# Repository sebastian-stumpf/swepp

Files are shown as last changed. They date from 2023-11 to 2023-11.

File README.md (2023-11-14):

# swepp

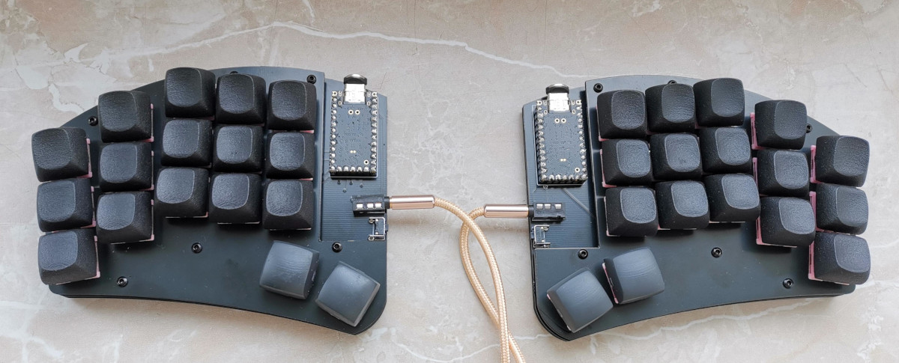
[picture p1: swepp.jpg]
swepp


## Attention

I'm a hobbyist/amateur at best. So there may be things that aren't optimized. That being said I've had the files
in the `gerbers/` directory manufactured at JLC with 1.6mm thickness and they work just fine with my fork of the qmk repository
directory. So if you decide to use this, then please be advised that I'm not providing any sort of liability and you should
exercise some caution.

## Case

There are three options for the case: The first one is a simple FR4 stack. You'll need some M2 spacers and screws to fix it all
together. Plates and bottoms are reversible. The second option is a simple tray case. You'll need M2 heat inserts and screws to
fix the plate to the bottom. If you don't like the 3d printed plate you can also use the FR4 plate with spacers in this case.
The final option is a massive gasket mounted case that hides the switches.

## BOM

| Quantity | Item | Comment |
| ---  | --- | --- |
| 2 | Helios or Liatris Controller | |
| 2 | IC-Sockets+Pins for MCU | Optional but recommended |
| 2 | TRRS Sockets | |
| 2 | SKHLLBA010 buttons | |
| 34 | MX Hotswap Sockets | |
| 34 | MX Switches + Keycaps | |
| 12 | M2 Screws | (countersunk for gasket case) |
| 12 | M2 heat inserts | Only for the 3d printed cases |

## Firmware

See [my fork](https://github.com/sebastian-stumpf/qmk_firmware/tree/sepp/keyboards/swepp) of the qmk repository. Nothing special here.
You can just copy the code over to your own repository and adjust the keymap.

## Feedback

I'm always happy to hear your opinions about this and if you decide to build this board then please do send me a picture of it.

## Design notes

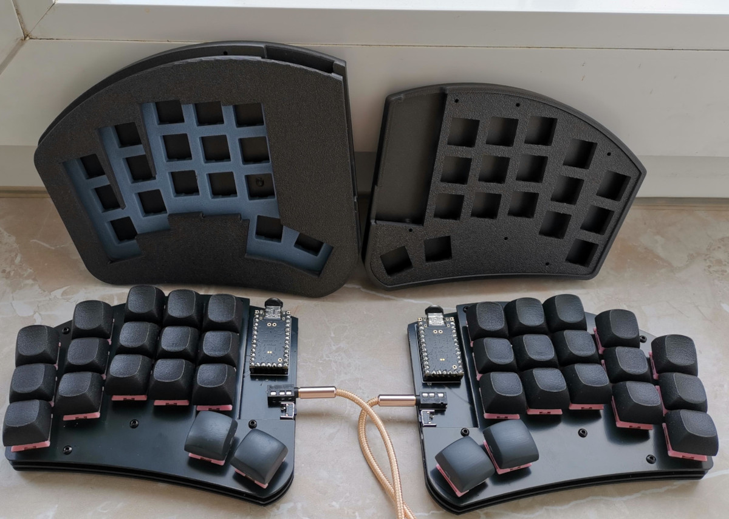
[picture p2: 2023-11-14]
case.jpg

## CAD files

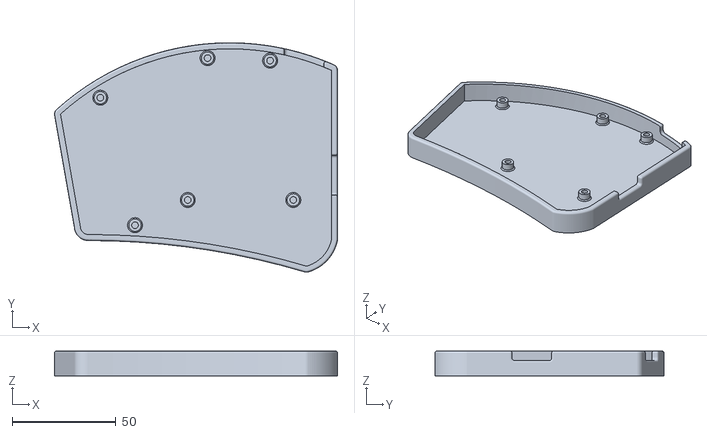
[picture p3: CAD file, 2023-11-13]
cad/case-tray-case.stl
136.2 x 110.4 x 12.0

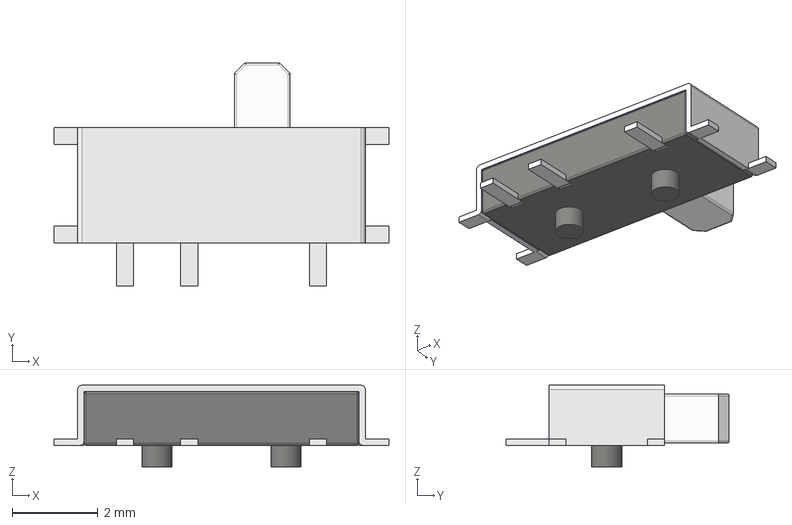
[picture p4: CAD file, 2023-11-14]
pcb/sepp/models/MSK12C02.step
7.80 x 5.20 x 1.90 mm

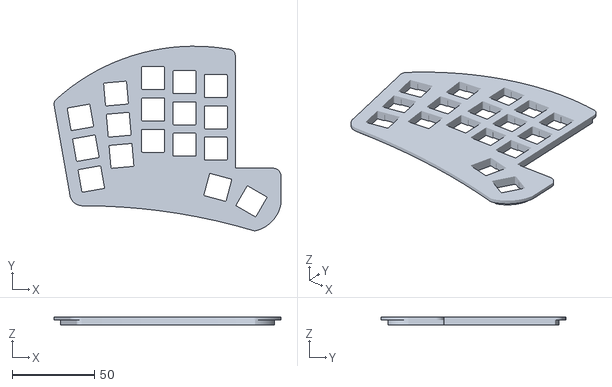
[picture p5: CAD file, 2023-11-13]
cad/case-gasket-plate.stl
138.2 x 112.3 x 5.00

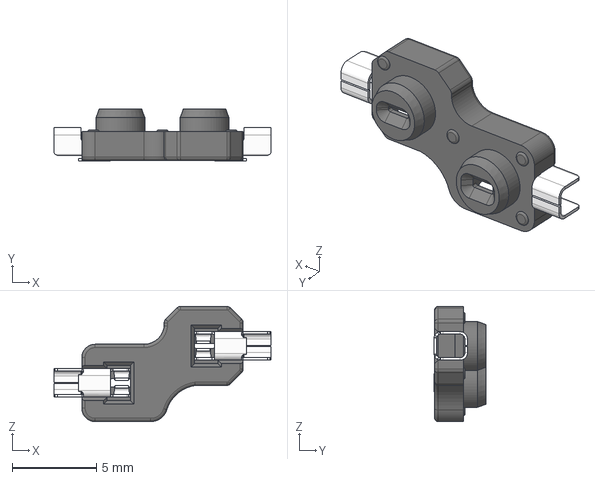
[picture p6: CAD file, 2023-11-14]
pcb/sepp/models/HS_Kailh_Choc.step
12.9 x 3.09 x 6.85 mm
pin x 2
socket

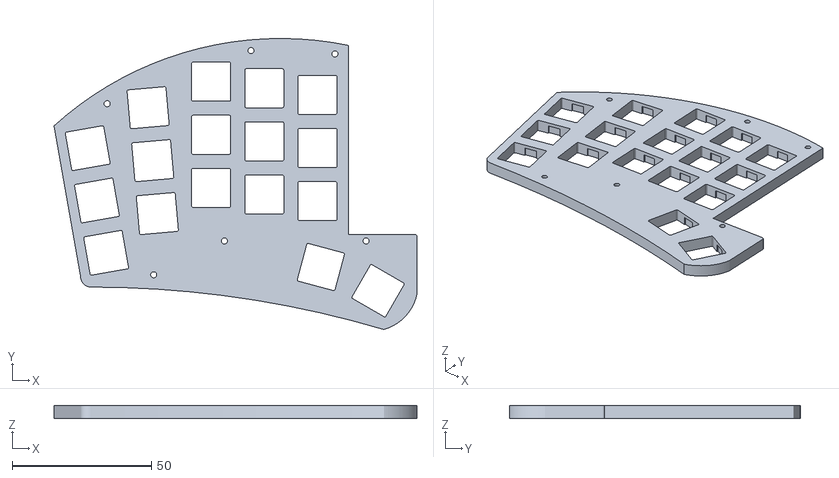
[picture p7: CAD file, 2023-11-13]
cad/case-tray-alternate-plate.stl
130.2 x 104.4 x 4.50

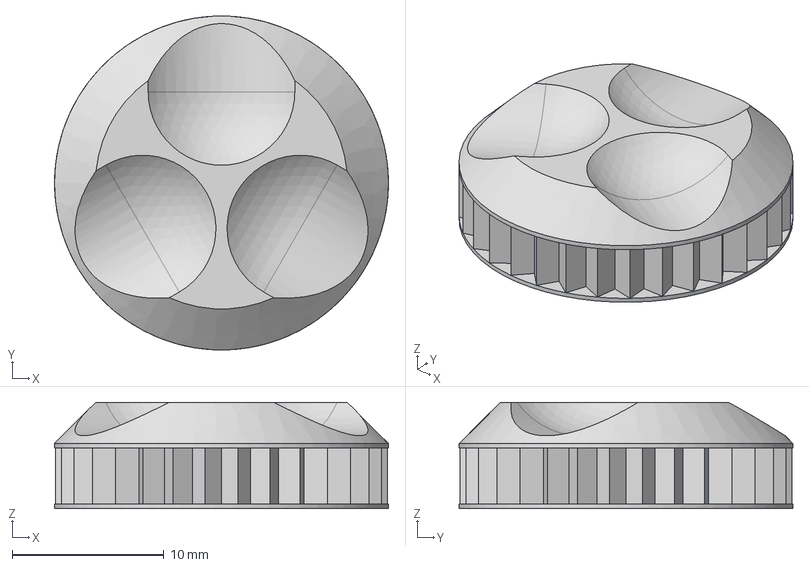
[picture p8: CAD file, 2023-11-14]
pcb/sepp/models/GEIST_EC12knob_v02_06.step
22.0 x 22.0 x 7.00 mm

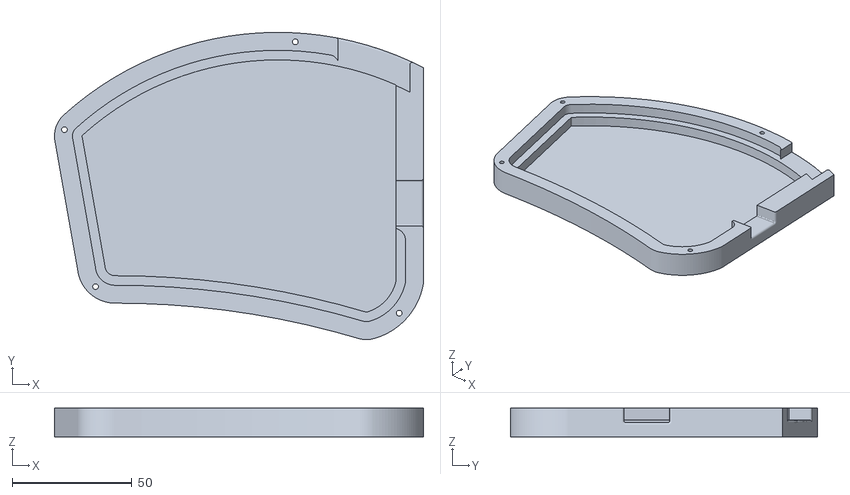
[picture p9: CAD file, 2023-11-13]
cad/case-gasket-case.stl
154.1 x 128.3 x 12.0

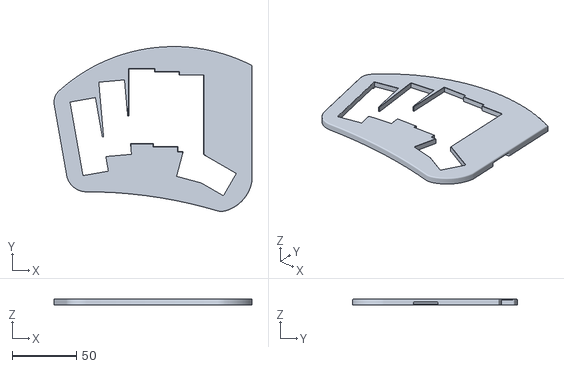
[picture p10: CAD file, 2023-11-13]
cad/case-gasket-shell.stl
154.1 x 128.3 x 5.00

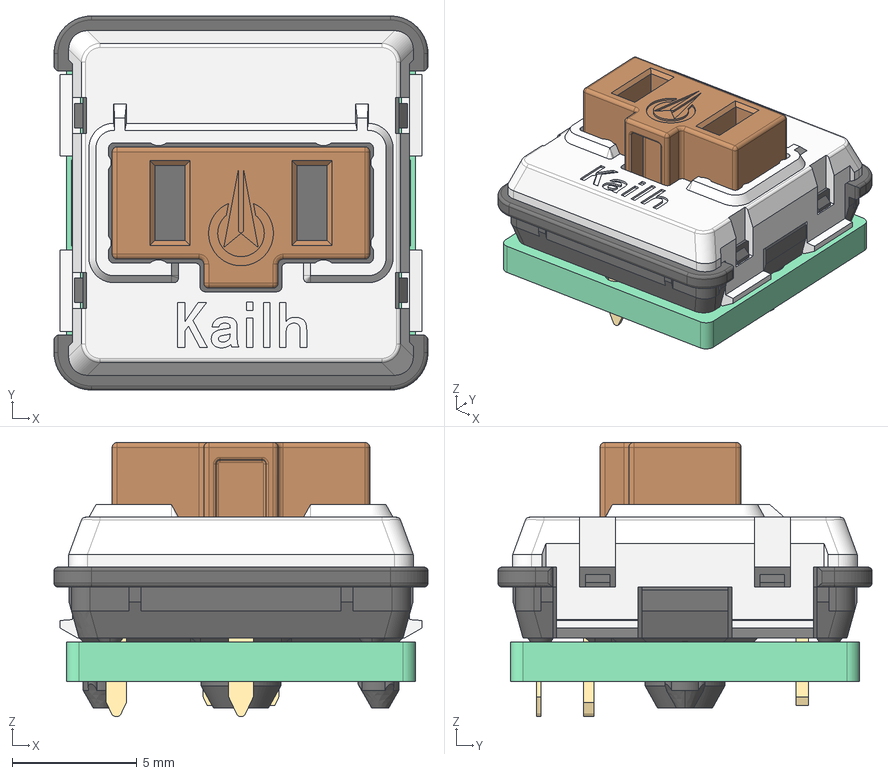
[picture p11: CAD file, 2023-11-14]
pcb/sepp/models/pg1350.step
15.0 x 15.0 x 11.0 mm

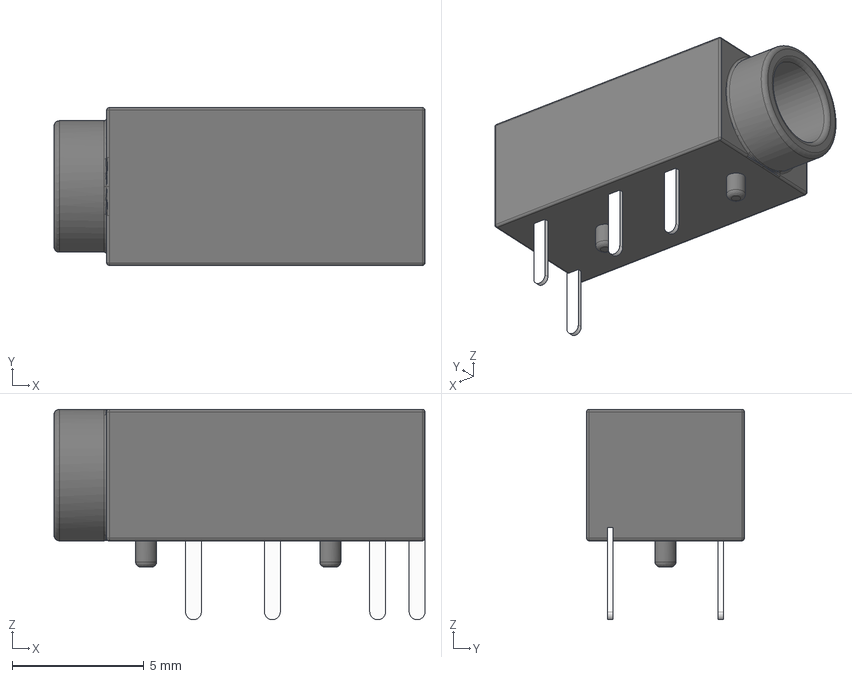
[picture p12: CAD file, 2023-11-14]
pcb/sepp/models/CON_MJ-4PP-9.step
14.1 x 6.00 x 8.00 mm

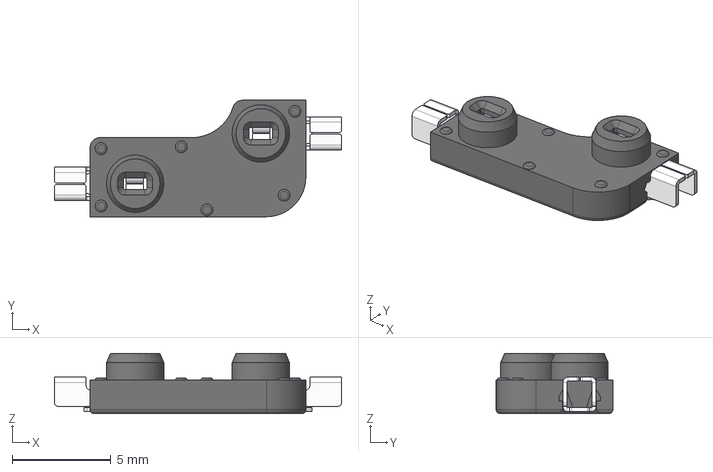
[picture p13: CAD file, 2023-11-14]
pcb/sepp/models/HS_Kailh_MX.step
14.5 x 5.89 x 3.05 mm
Contact x 2

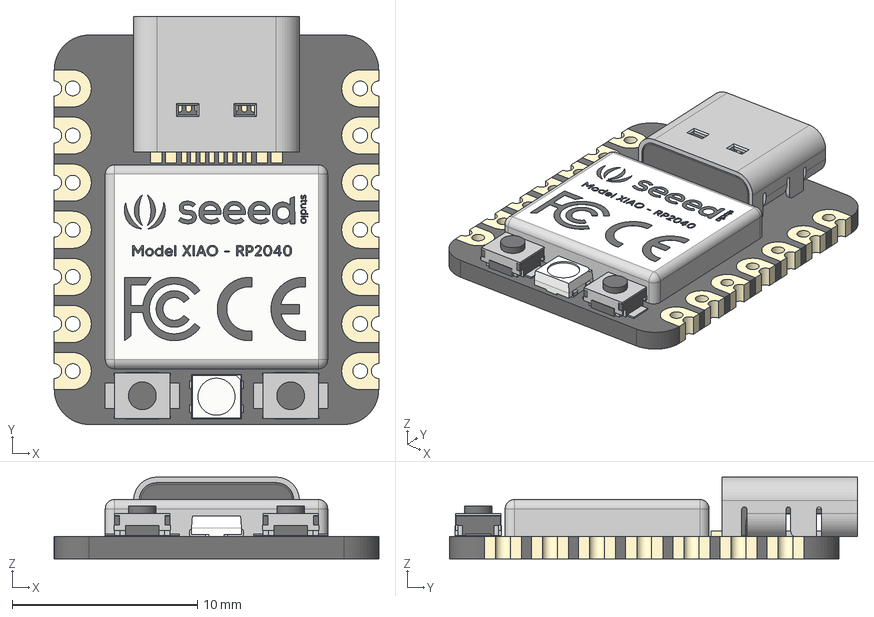
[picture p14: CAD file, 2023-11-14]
pcb/sepp/models/xiao_rp2040.step
17.5 x 22.0 x 4.40 mm
type-c v2
smd_button v3
DOUT
DIN
VSS
VDD
smd_button v3(Mirror)

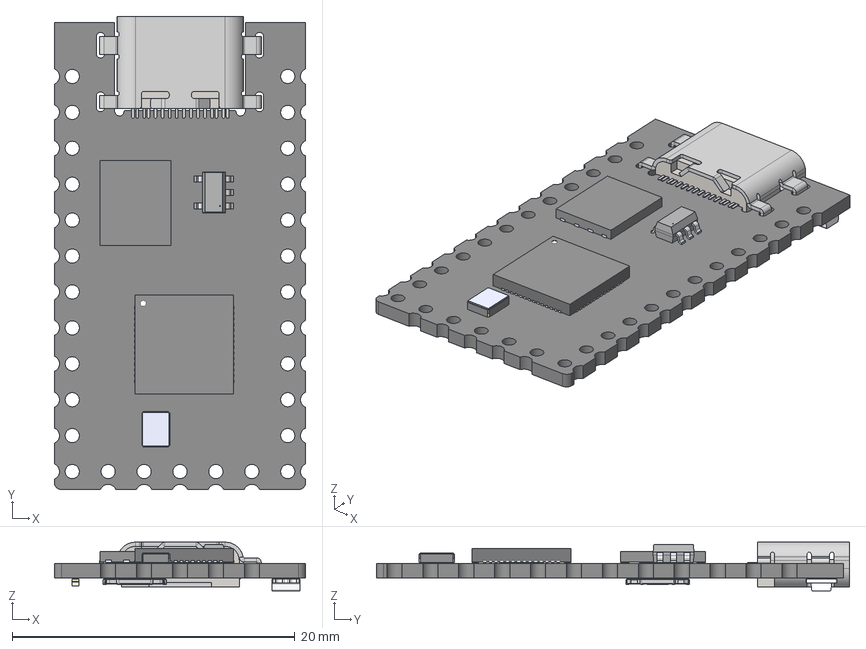
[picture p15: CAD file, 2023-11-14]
pcb/sepp/models/Liatris.step
17.8 x 33.5 x 3.44 mm
RP2040 PCB

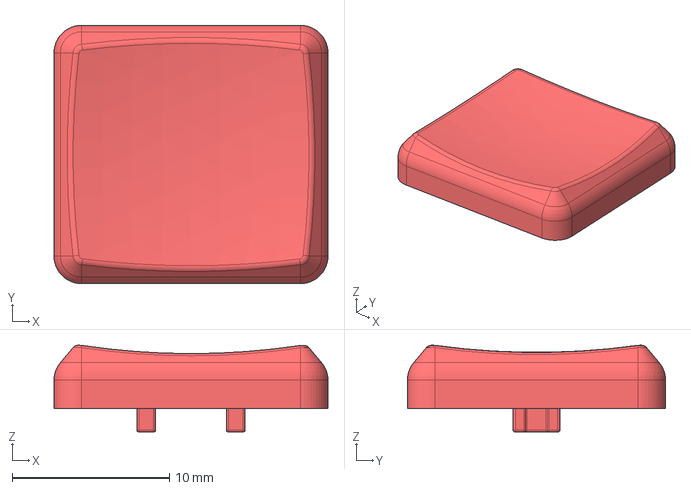
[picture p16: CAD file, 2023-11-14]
pcb/sepp/models/MBK-1u.step
17.4 x 16.4 x 5.52 mm

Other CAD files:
pcb/sepp/models/SW_MSK12C02.step
pcb/sepp/models/fpc-connector-breakout.step
pcb/sepp/models/tact-switch.step
pcb/sepp/models/pg1350-mbk.step
pcb/sepp/models/EC11-THT-15F-black.step
pcb/sepp/models/EC12E-085.step
pcb/sepp/models/LED_SK6812MINI-E.step
pcb/sepp/models/SKRTLAE010.step
pcb/sepp/models/SW_PUSH_6mm.step
pcb/sepp/models/SW_SKHLLC.step
pcb/sepp/models/abomination-trackpad-holder.step
pcb/sepp/models/cherry mx.STEP
pcb/sepp/models/mx_kecap.step

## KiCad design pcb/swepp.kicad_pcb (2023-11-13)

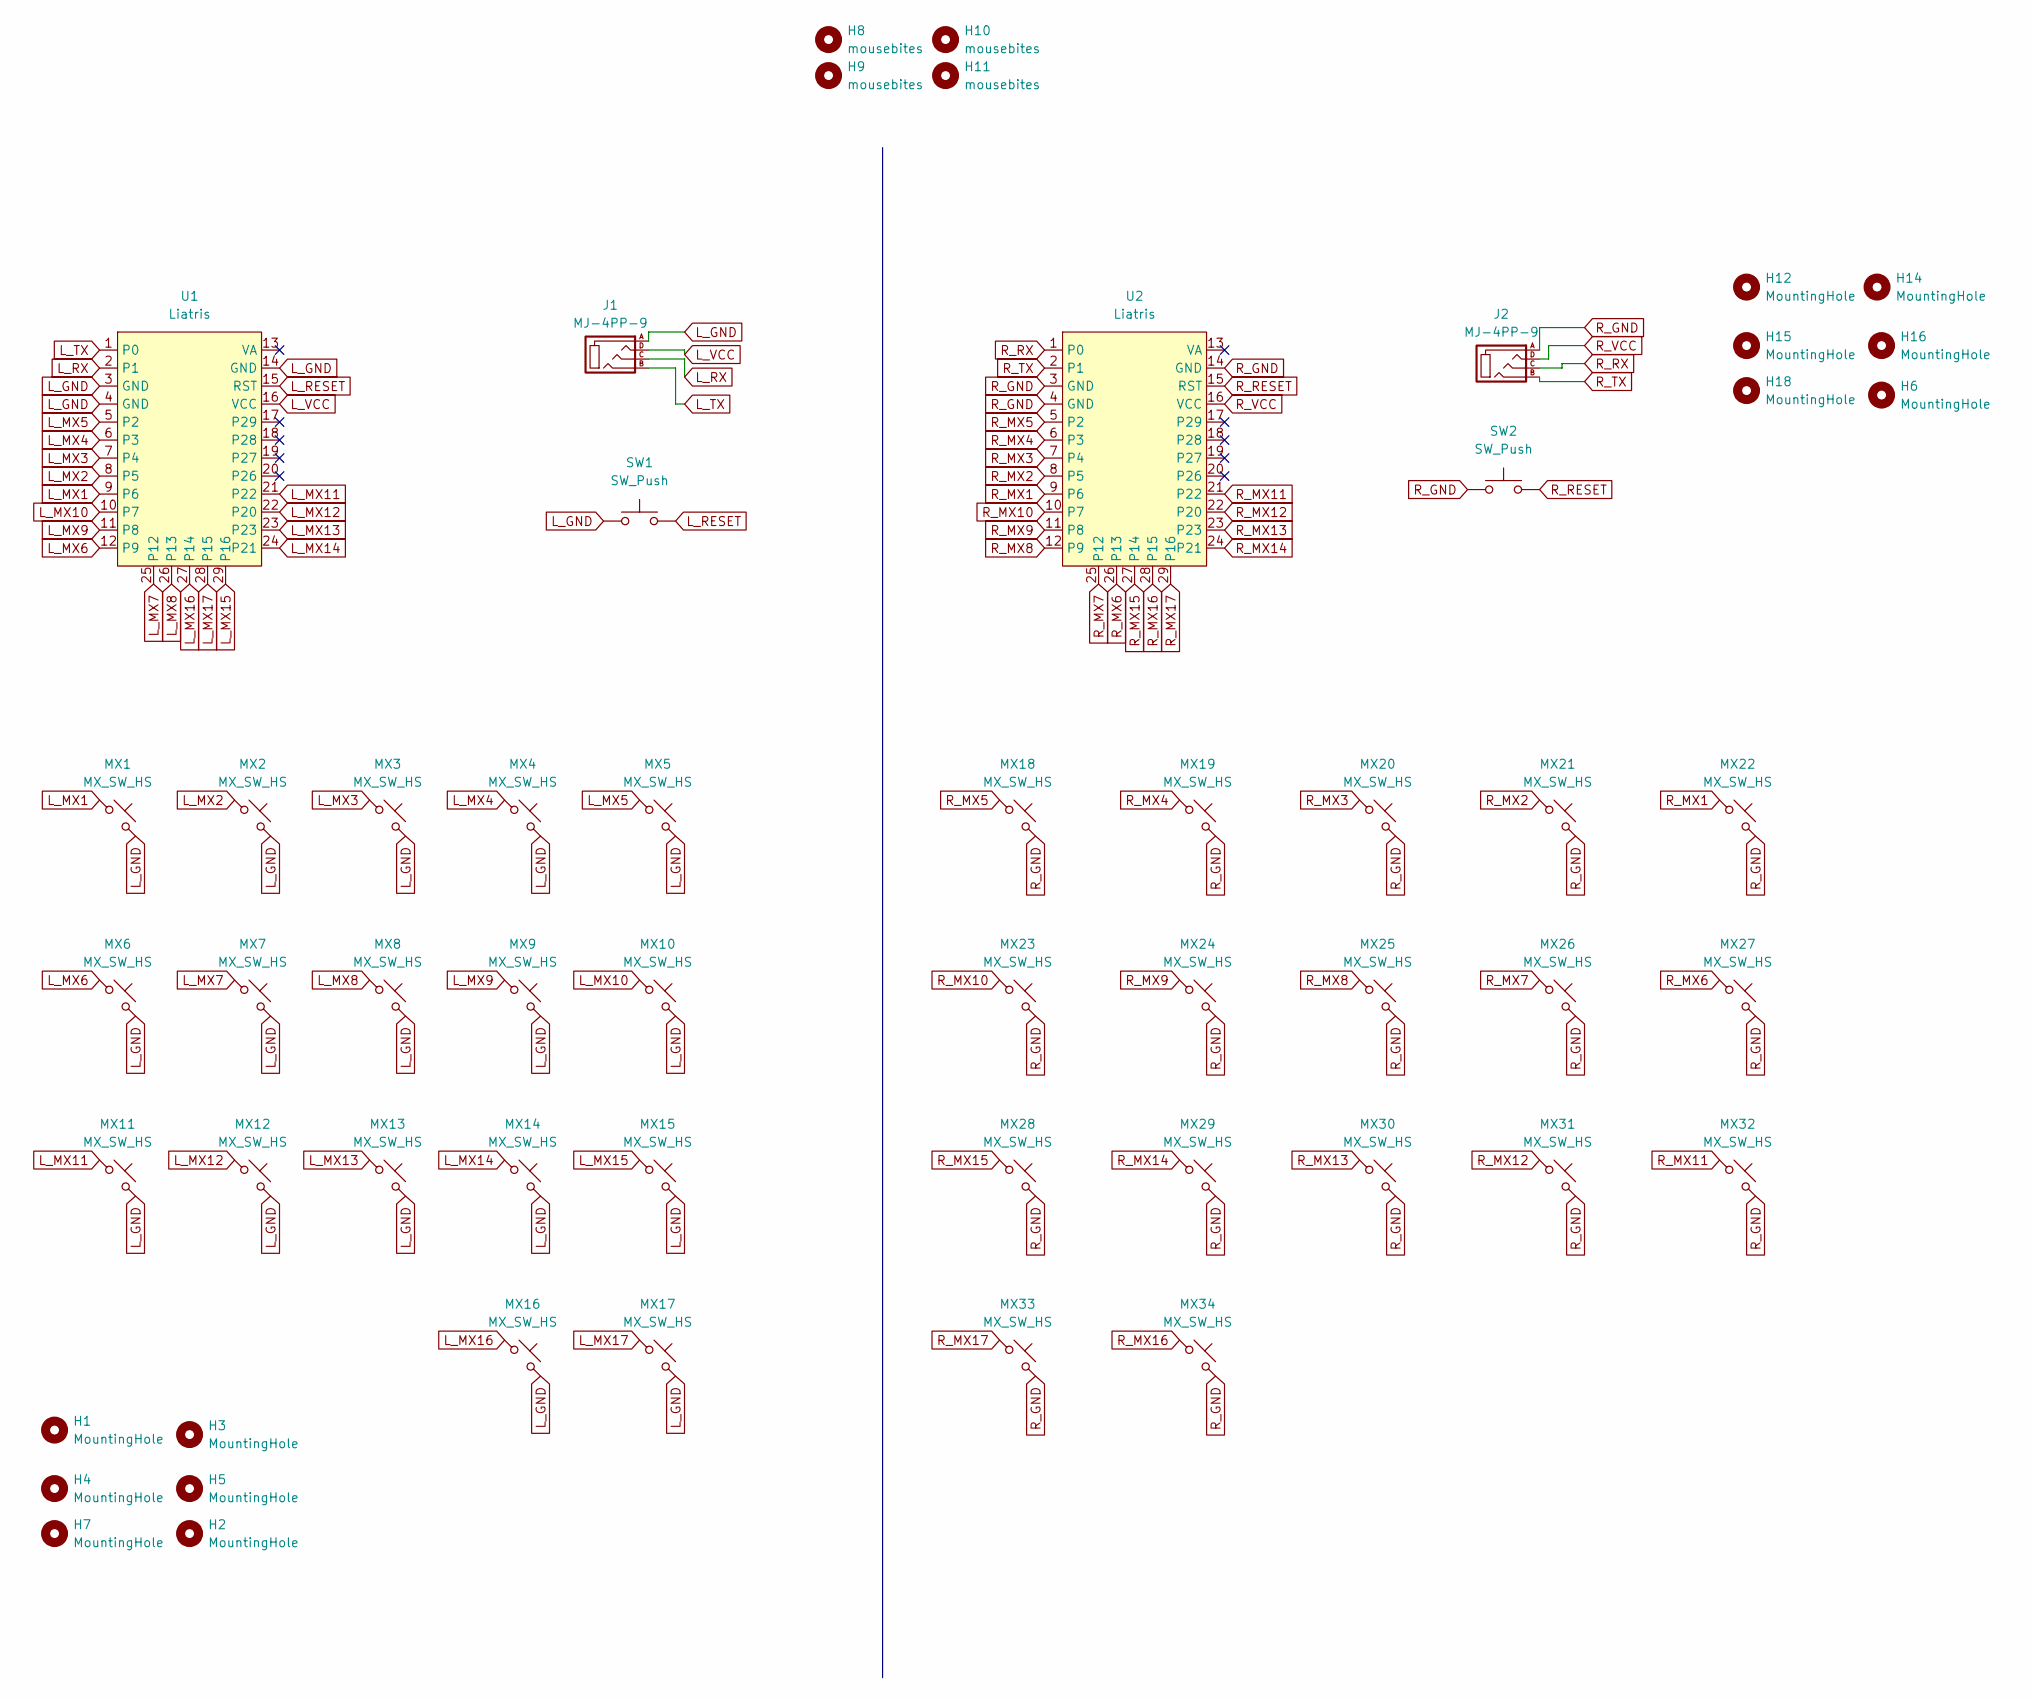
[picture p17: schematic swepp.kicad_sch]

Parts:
H1, H2, H3, H4, H5, H6, H7, H12, H14, H15, H16, H18: MountingHole; MountingHole_2.2mm_M2_DIN965
H8, H9, H10, H11: mousebites; breakaway-mousebites
J1, J2: MJ-4PP-9
MX1, MX2, MX3, MX4, MX5, MX6, MX7, MX8, MX9, MX10, MX11, MX12, MX13, MX14, MX15, MX16, MX17, MX18, MX19, MX20, MX21, MX22, MX23, MX24, MX25, MX26, MX27, MX28, MX29, MX30, MX31, MX32, MX33, MX34: MX_SW_HS; SW_MX_HS_1u
SW1, SW2: SW_Push; top_reset
U1, U2: Liatris; Liatris_AH_USBdn

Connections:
L_GND: J1.A, MX1.2, MX2.2, MX3.2, MX4.2, MX5.2, MX6.2, MX7.2, MX8.2, MX9.2, MX10.2, MX11.2, MX12.2, MX13.2, MX14.2, MX15.2, MX16.2, MX17.2, SW1.1, U1.3 (GND), U1.4 (GND), U1.14 (GND)
L_MX1: MX1.1, U1.9 (P6)
L_MX2: MX2.1, U1.8 (P5)
L_MX3: MX3.1, U1.7 (P4)
L_MX4: MX4.1, U1.6 (P3)
L_MX5: MX5.1, U1.5 (P2)
L_MX6: MX6.1, U1.12 (P9)
L_MX7: MX7.1, U1.25 (P12)
L_MX8: MX8.1, U1.26 (P13)
L_MX9: MX9.1, U1.11 (P8)
L_MX10: MX10.1, U1.10 (P7)
L_MX11: MX11.1, U1.21 (P22)
L_MX12: MX12.1, U1.22 (P20)
L_MX13: MX13.1, U1.23
L_MX14: MX14.1, U1.24 (P21)
L_MX15: MX15.1, U1.29 (P16)
L_MX16: MX16.1, U1.27 (P14)
L_MX17: MX17.1, U1.28 (P15)
L_RESET: SW1.2, U1.15 (RST)
L_RX: J1.C, U1.2 (P1)
L_TX: J1.B, U1.1 (P0)
L_VCC: J1.D, U1.16 (VCC)
R_GND: J2.A, MX18.2, MX19.2, MX20.2, MX21.2, MX22.2, MX23.2, MX24.2, MX25.2, MX26.2, MX27.2, MX28.2, MX29.2, MX30.2, MX31.2, MX32.2, MX33.2, MX34.2, SW2.1, U2.3 (GND), U2.4 (GND), U2.14 (GND)
R_MX1: MX22.1, U2.9 (P6)
R_MX2: MX21.1, U2.8 (P5)
R_MX3: MX20.1, U2.7 (P4)
R_MX4: MX19.1, U2.6 (P3)
R_MX5: MX18.1, U2.5 (P2)
R_MX6: MX27.1, U2.26 (P13)
R_MX7: MX26.1, U2.25 (P12)
R_MX8: MX25.1, U2.12 (P9)
R_MX9: MX24.1, U2.11 (P8)
R_MX10: MX23.1, U2.10 (P7)
R_MX11: MX32.1, U2.21 (P22)
R_MX12: MX31.1, U2.22 (P20)
R_MX13: MX30.1, U2.23
R_MX14: MX29.1, U2.24 (P21)
R_MX15: MX28.1, U2.27 (P14)
R_MX16: MX34.1, U2.28 (P15)
R_MX17: MX33.1, U2.29 (P16)
R_RESET: SW2.2, U2.15 (RST)
R_RX: J2.C, U2.1 (P0)
R_TX: J2.B, U2.2 (P1)
R_VCC: J2.D, U2.16 (VCC)

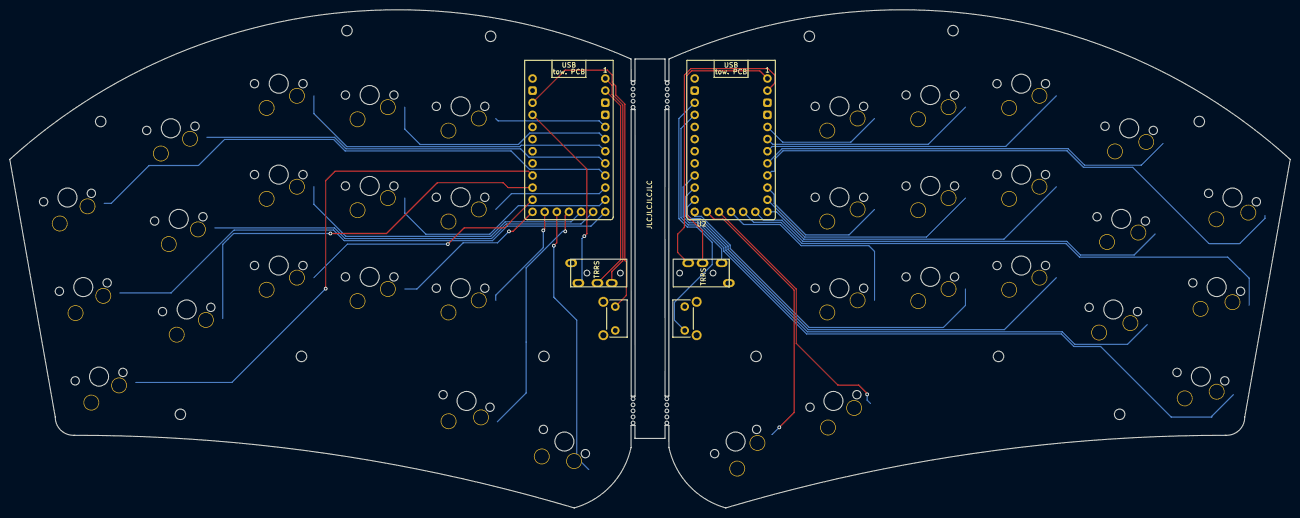
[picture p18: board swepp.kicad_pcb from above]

Board: 2 copper layers, 268.3 x 104.4 mm, 56 parts (0 on the bottom side), 44 nets.
